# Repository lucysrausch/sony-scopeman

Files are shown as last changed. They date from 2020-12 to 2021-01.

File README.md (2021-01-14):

# Sony-Scopeman
Hardware Design files of a replacement mainboard for the Sony Watchman FD-10. This turns it into a bluetooth and WiFi-enabled vector display.

# Features
There are two modes which can be selected via the power switch. 
* In "Audio" mode, the ESP32 acts as a bluetooth speaker. Play back audio files from your smartphone or laptop to hear and see the soundwaves. You can change the size by adjusting the playback volume

Demo: https://twitter.com/FauthNiklas/status/1337467949318279170
* In "Video" mode, the ESP32 renders the result of the Lorenz Attractor equation. You can change the simulation speed using the "Tune" knob.

Demo: https://twitter.com/FauthNiklas/status/1339650704584171522

# Instructions

You'll need:
* Sony Watchman Model FD-10
* Pre-assembled replacemend mainboard (eg. from JLCPCB assembly)
* Two 803040 (1000mAh) LiIon batterys with JST-PH connector

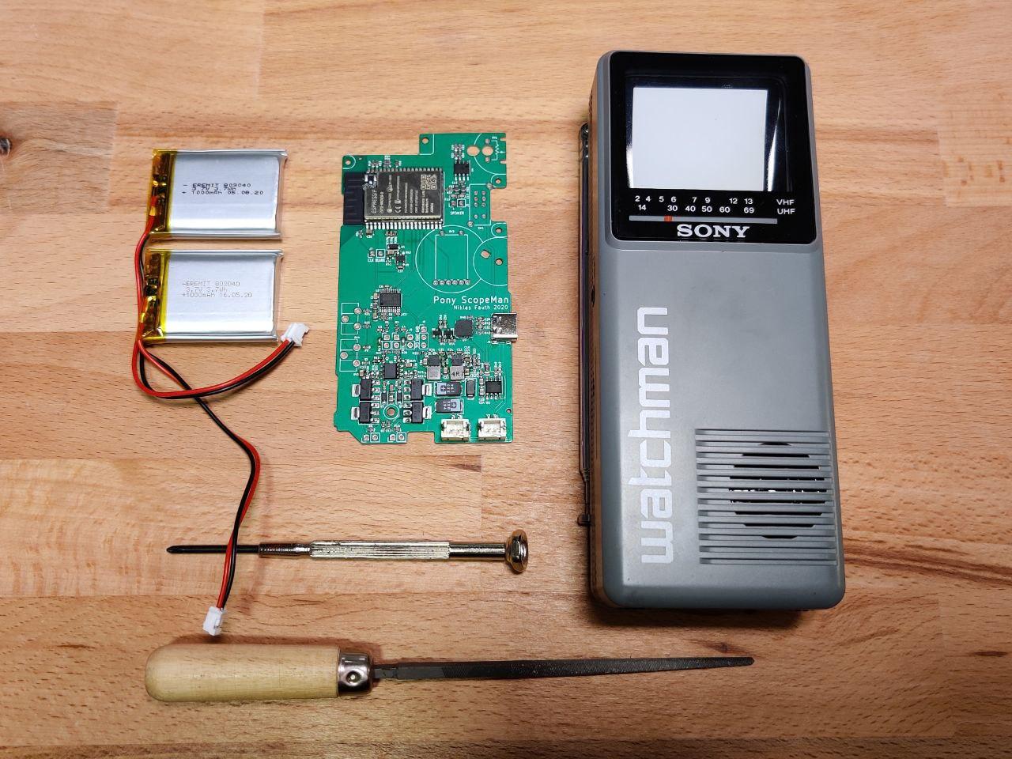
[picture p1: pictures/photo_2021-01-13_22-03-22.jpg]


Open the Sony Watchman and unscrew the original mainboard. Make sure to keep all the screws in a safe place.

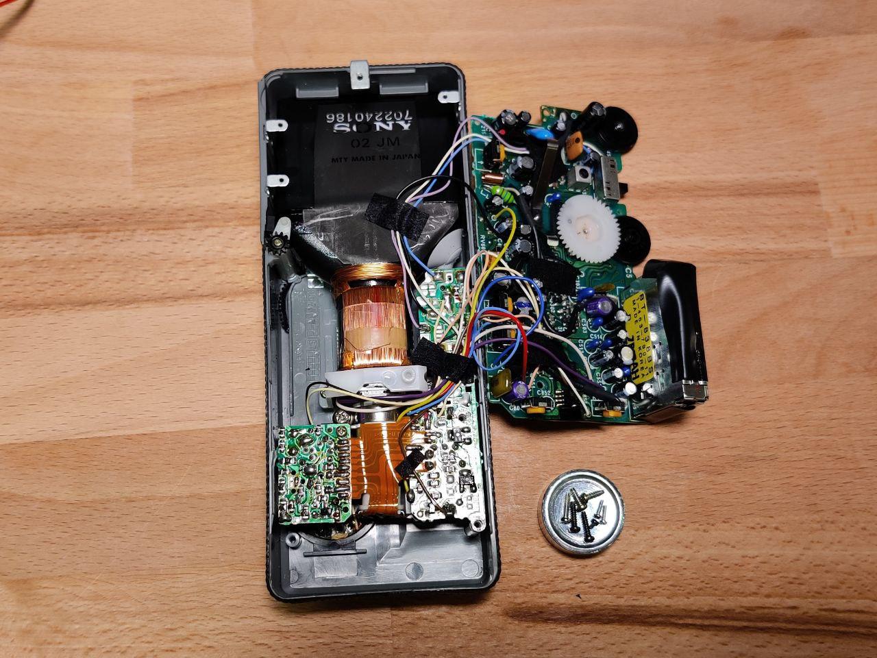
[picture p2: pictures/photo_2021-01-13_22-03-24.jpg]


Unsolder all wires from the mainboard.

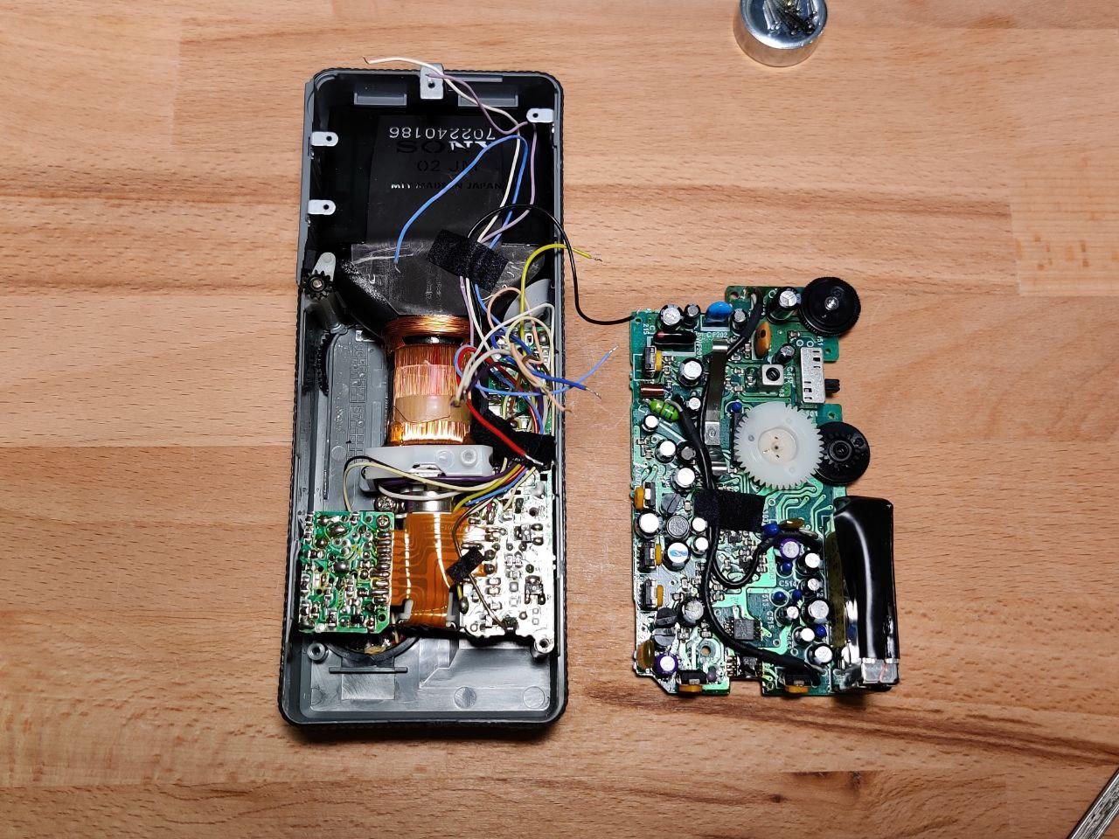
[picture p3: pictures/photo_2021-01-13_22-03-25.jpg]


Unsolder (and unscrew) these components from the mainboard. We'll need them for our replacement.

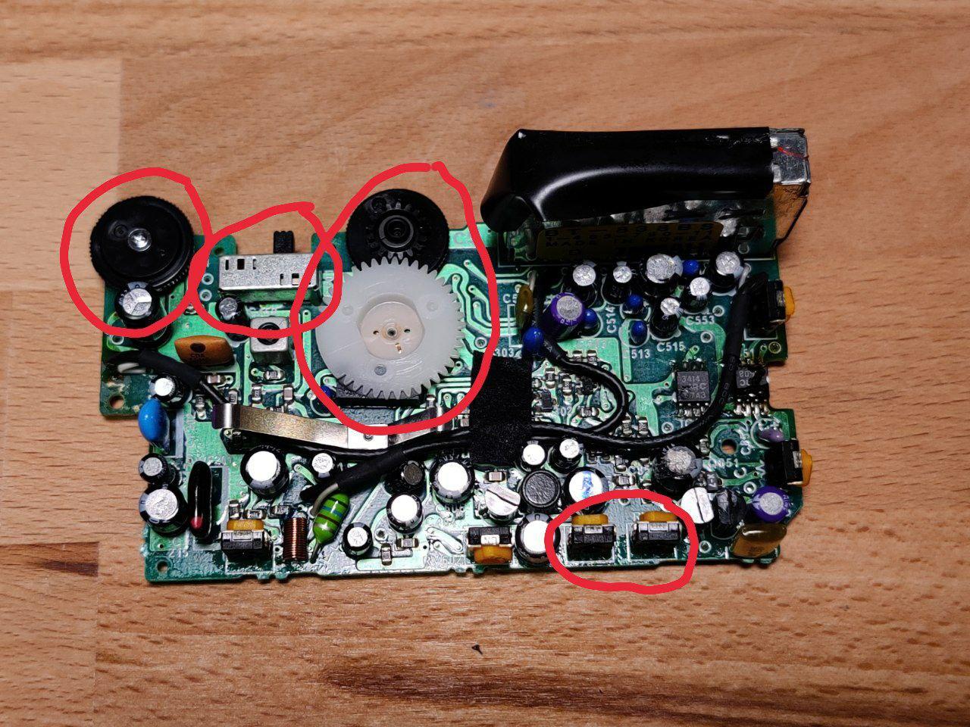
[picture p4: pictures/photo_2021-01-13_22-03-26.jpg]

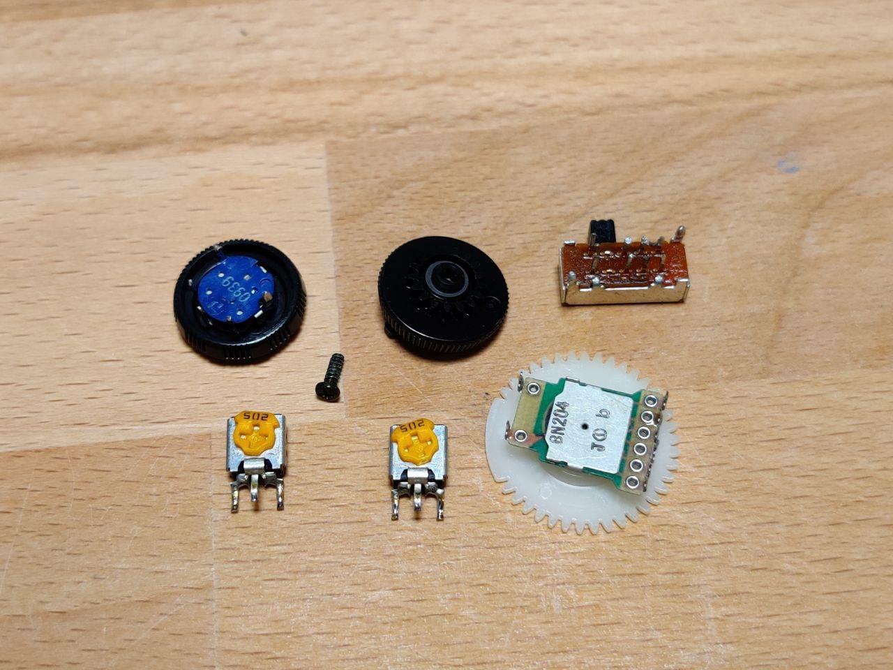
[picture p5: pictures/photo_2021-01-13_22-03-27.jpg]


Install all unsoldered components on the replacement mainboard.

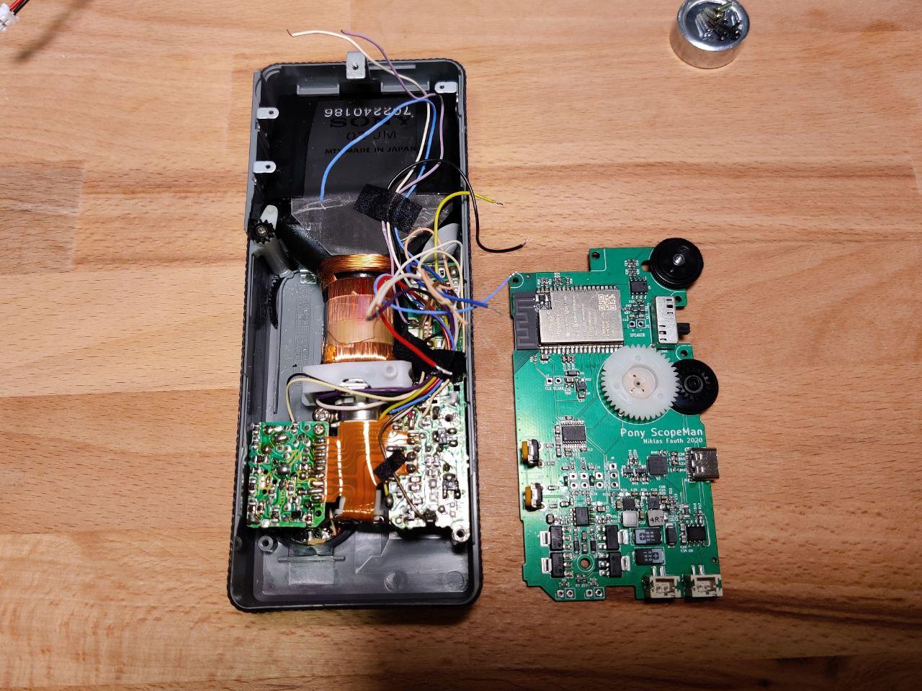
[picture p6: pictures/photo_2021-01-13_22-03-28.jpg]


Unsolder the speaker cables (black and white) from the flyback PCB. Solder them to the replacement PCB (take care of polarity. White is closer to the ESP32).
Remove all other cables from the flyback PCB except for blue, yellow, black and purple.

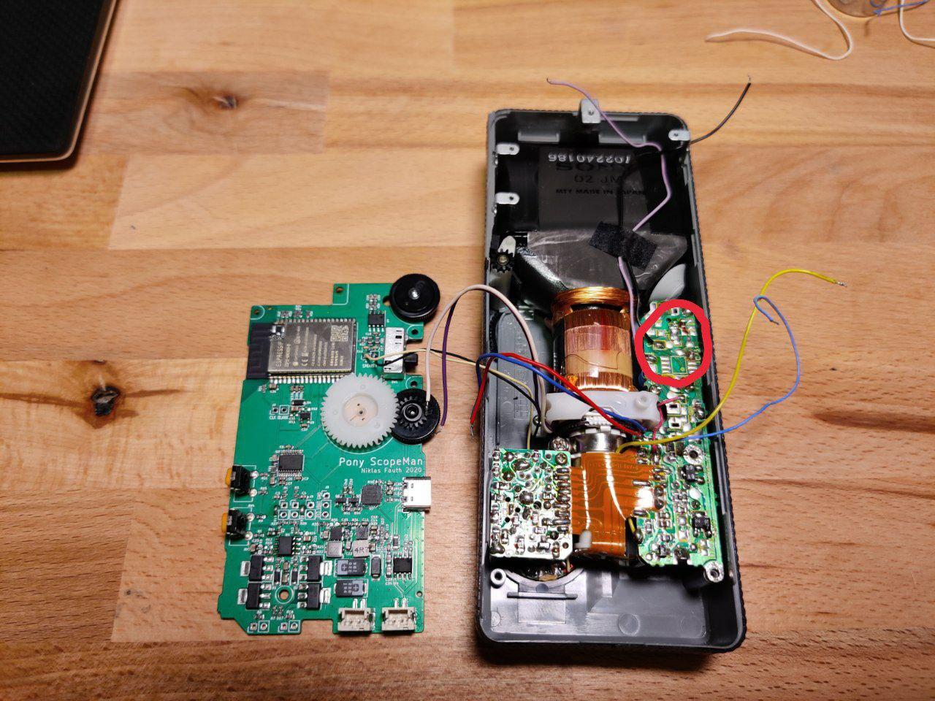
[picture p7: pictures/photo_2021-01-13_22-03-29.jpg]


Solder the blue (flyback signal) and yellow (blanking) to the new mainboard.
Do the same for purple (supply) and black (GND).

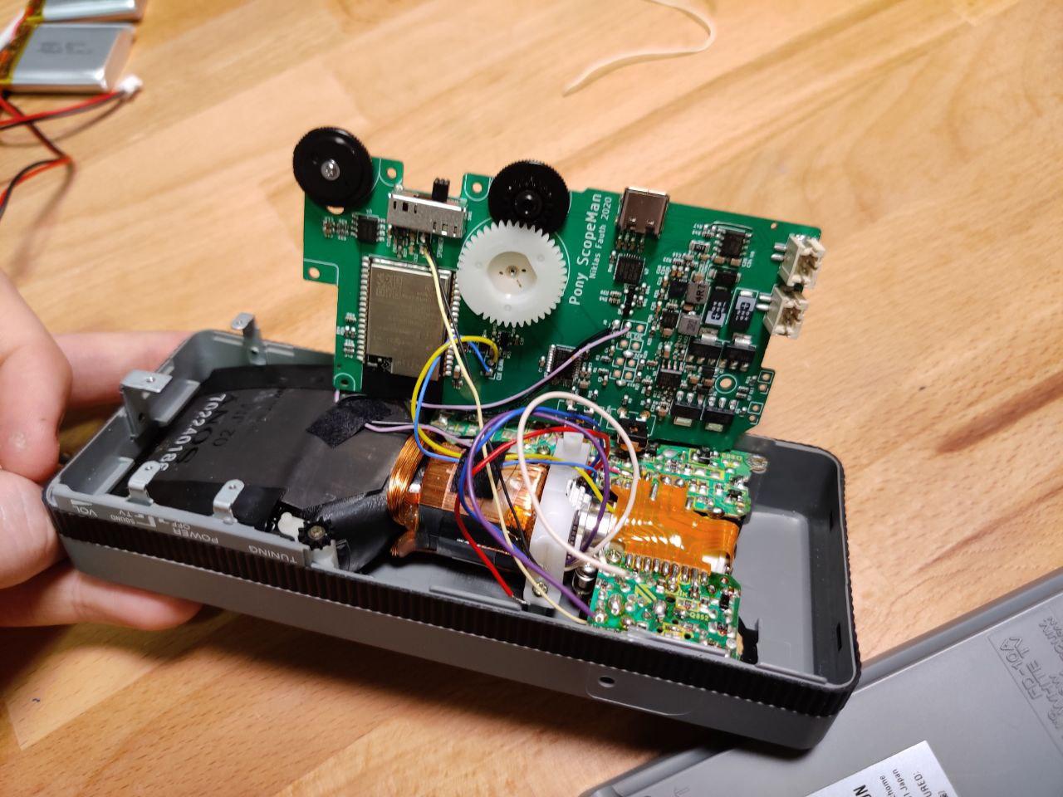
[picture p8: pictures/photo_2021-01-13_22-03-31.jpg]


Next, connect the deflection coil wires (purple, white, red and blue). 

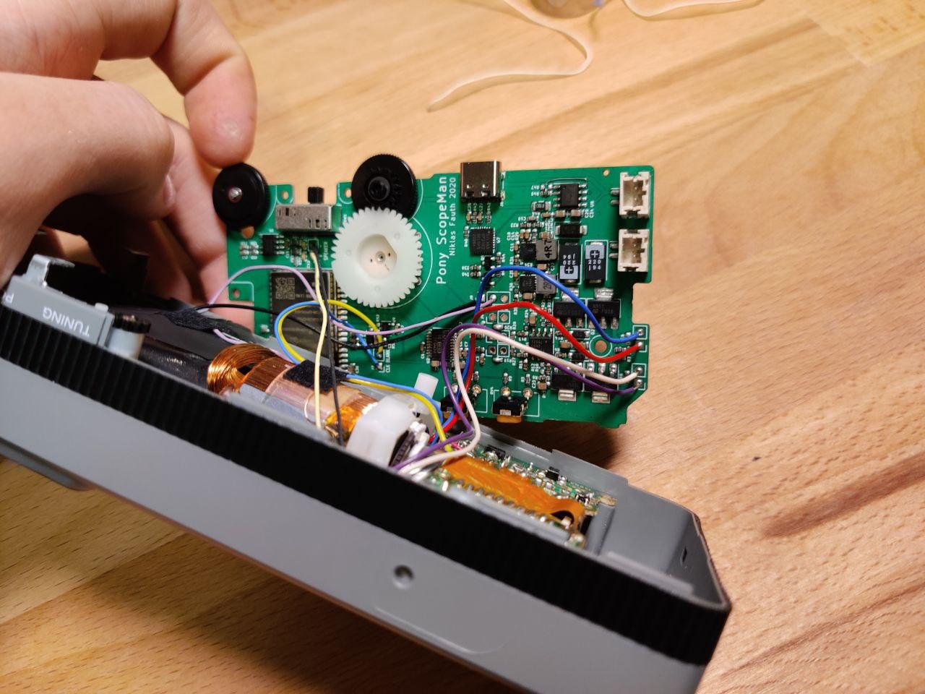
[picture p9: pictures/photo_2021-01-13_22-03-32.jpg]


You can now plug in the batteries (make sure the watchman is turned off) and screw the mainboard back in place. You need two screws for this (mind the arrows on the back of the PCB).

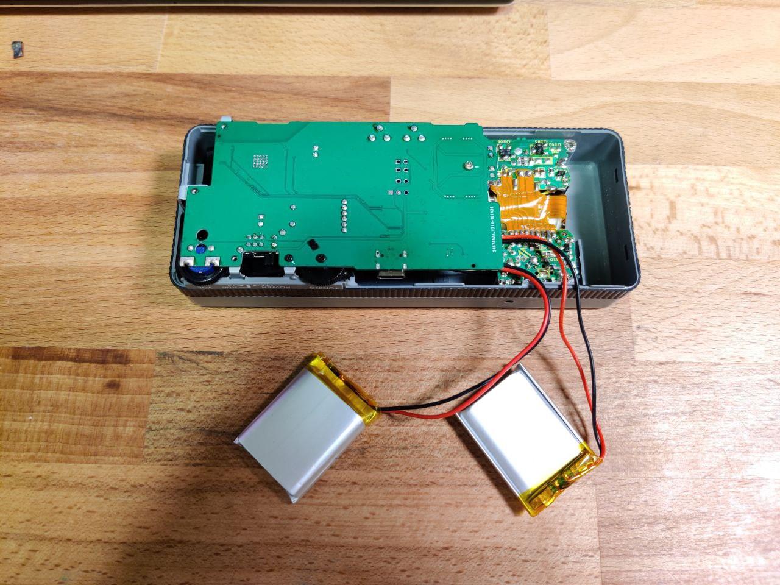
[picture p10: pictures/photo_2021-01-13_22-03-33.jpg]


Now you can add a slothole to the lower half of the case for the USB type C jack. You also need to brake away some plastics to make space for the new batteries. No worries, if done correctly this won't be visible from the outside and the battery cover will still close.

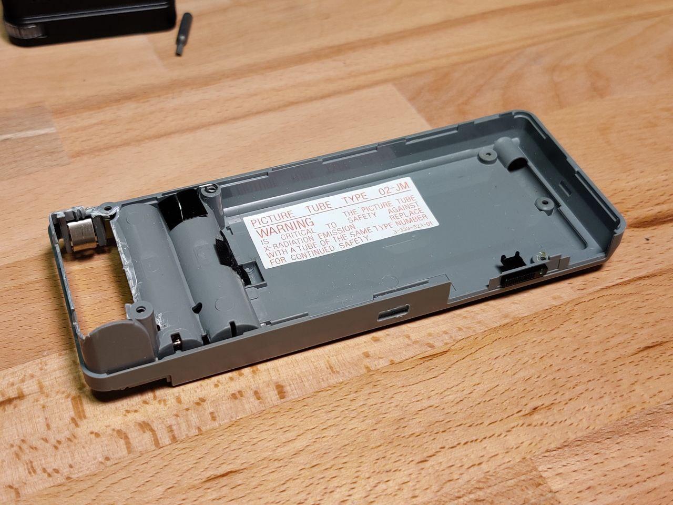
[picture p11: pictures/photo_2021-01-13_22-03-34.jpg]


That's it! Before you screw the watchman back together and store the batteries behind the cover, you may want to adjust the two potentiometers on the mainboard to center the image. But first you need to flash the firmware. Turn on the watchman and connect it via USB. You can then flash the ESP32 using the Arduino IDE (make sure to select "Board: ESP Wrover Module").

You might also need to readjust the focus. This can be done from outside using the original focus knob (hidden behind a small hole at the side).

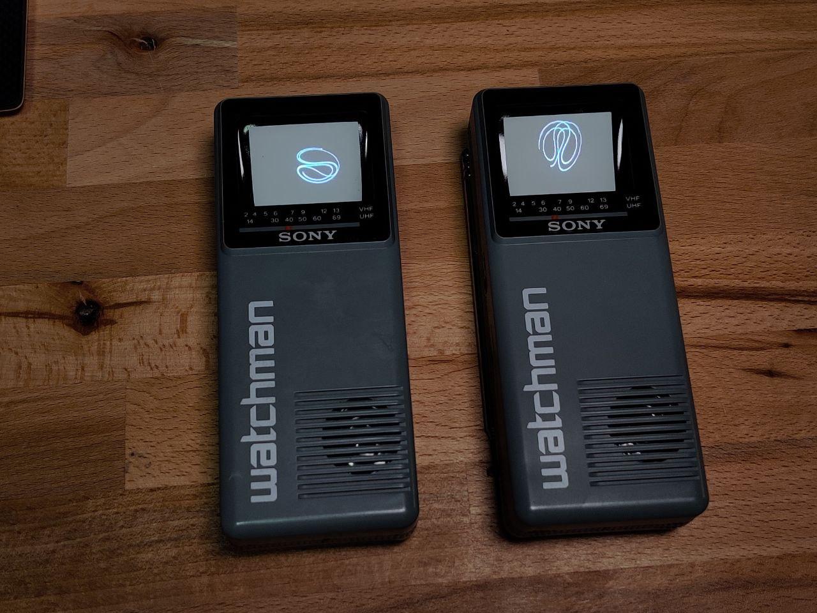
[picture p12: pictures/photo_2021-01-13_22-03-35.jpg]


# Credits
Deflection coil drivers inspired by http://www.e-basteln.de/file/asteroids/Vectrex_XY_Driver.pdf

A2DP Arduino lib for ESP32: https://github.com/pschatzmann/ESP32-A2DP

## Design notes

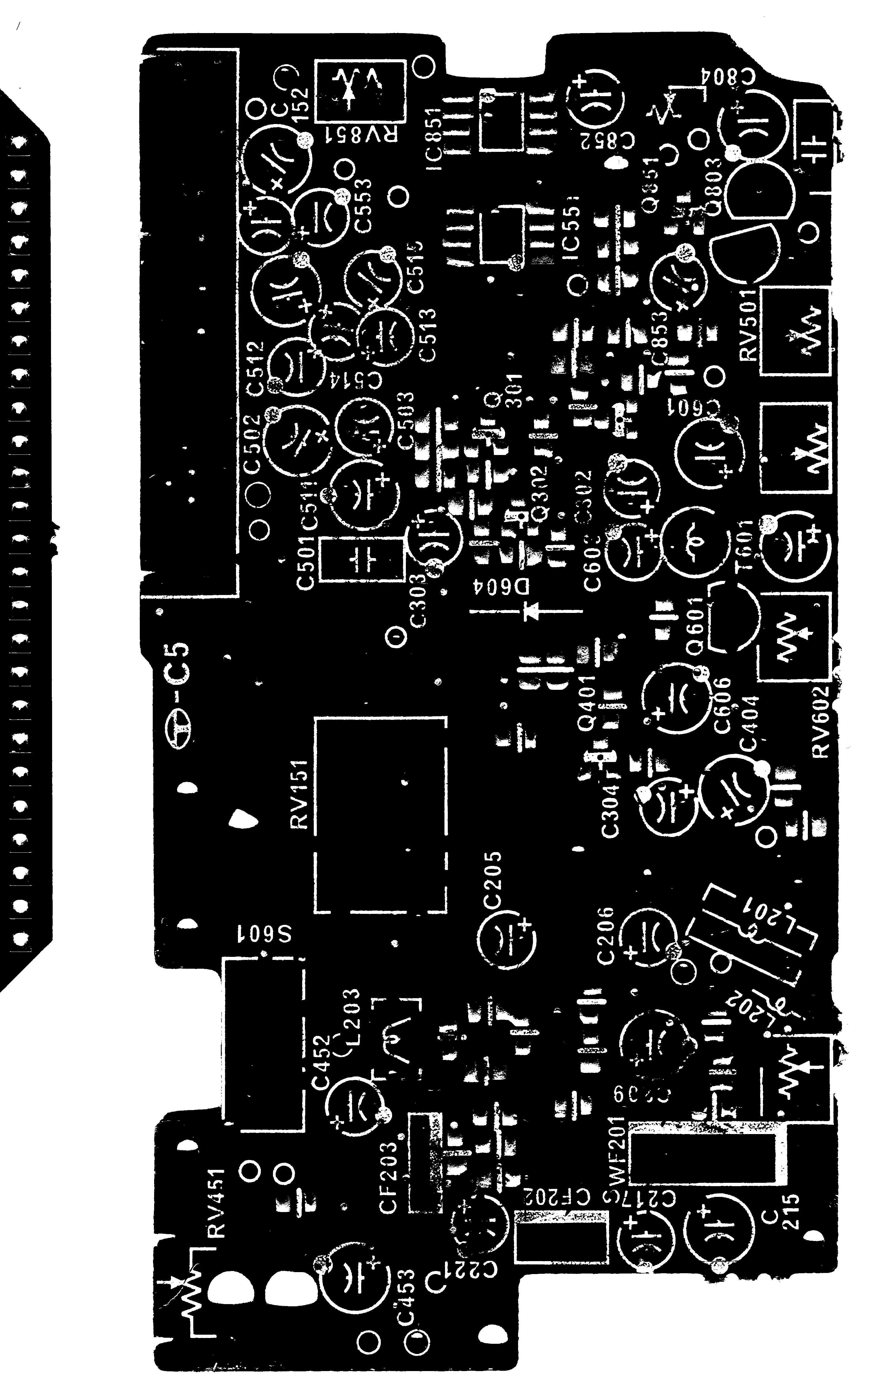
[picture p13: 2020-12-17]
hardware/scans/top.png

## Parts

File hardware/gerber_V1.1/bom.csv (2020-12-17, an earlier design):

Comment | Designator | Footprint | LCSC Part # | LCSC Part Type
100n | C37,C30,C28,C27,C26,C25,C19,C14,C11,C8,C2 | 0603_C | C14663
1k | R55,R54,R17,R13,R7,R2 | 0603_R | C21190
TPS63001 | U6 | Texas_DRC0010J_ThermalVias
TPS63700DRCT | U5 | Texas_DRC0010J_ThermalVias
10u | C36,C35,C34,C31,C29,C24,C23,C22,C21,C20,C9,C5,C1 | 0805_C | C15850
TP4056-otter | U8 | SOIC-8-1EP_3.9x4.9mm_P1.27mm_EP2.41x3.3mm | C16581
0.27R | R46 | R_1206_3216Metric | C25334
LiIon | BT1,BT2 | JST_PH_B2B-PH-SM4-TB_1x02-1MP_P2.00mm_Vertical
MMBT3906 | Q10,Q8 | SOT-23 | C8542
MMBT3904 | Q9,Q7,Q6,Q5 | SOT-23 | C2150
100u | C33,C32 | CP_EIA-7343-43_Kemet-X
10k | RV4,RV3 | Potentiometer_ACP_CA9-H3,8_Horizontal
2.2u | L2 | Inductor_4040
4.7u | L1 | Inductor_4040
GND | J9 | PinHeader_1x02_P2.54mm_Vertical
PWR | J8 | PinHeader_1x03_P2.54mm_Vertical
BLK+CLK | J7 | PinHeader_1x02_P2.54mm_Vertical
SPEAKER | J5 | PinHeader_1x02_P2.54mm_Vertical
COIL_Y | J4 | PinHeader_1x02_P2.54mm_Vertical
EXT_Y | J3 | PinHeader_1x02_P2.54mm_Vertical
COIL_X | J2 | PinHeader_1x02_P2.54mm_Vertical
EXT_X | J1 | PinHeader_1x02_P2.54mm_Vertical
601 | FB3,FB2,FB1 | L_0805_2012Metric | C1017
4148 | D4,D2,D1 | D_SOD-123 | C81598
SL03 | D3 | D_SMA | C8678
LMV321 | U9 | SOT-23-5
CP2102N-A01-GQFN28 | U7 | QFN-28-1EP_5x5mm_P0.5mm_EP3.35x3.35mm | C6568
PAM8302AAD | U4 | SOIC-8_150mil | C112137
ESP32-WROVER | U3 | ESP32-WROVER
PCM5102 | U2 | TSSOP-20_4.4x6.5mm_P0.65mm | C107671
OPA2683 | U1 | SOIC-8_150mil
TBD | R53 | 0603_R
DNP | R52,R36,R24,R20,R19,R11 | 0603_R
22 | R51 | 0603_R | C23345
10k | R50,R47,R45,R44,R41,R40,R39 | 0603_R | C25804
1.2k | R49 | 0603_R | C22765
100k | R48,R38,R37,R33,R23 | 0603_R | C25803
5.1k | R43,R42 | 0603_R | C23186
0R | R35 | 0603_R | C21189
100 | R34,R32,R30 | 0603_R | C22775
10 | R31,R14,R4 | 0603_R | C22859
120k | R29 | 0603_R | C25808
22k | R28,R27,R21,R15,R9,R5 | 0603_R | C31850
220k | R26 | 0603_R | C22961
470 | R25,R22,R12,R10,R3,R1 | 0603_R | C23179
1R | R18,R8 | 0603_R | C22936
3.3k | R16,R6 | 0603_R | C22978
PZT3906 | Q4,Q2 | SOT-223-3_TabPin2
PZT3904 | Q3,Q1 | SOT-223-3_TabPin2
USB_C_Receptacle_USB2.0 | J6 | USB_C_Receptacle_Palconn_UTC16-G
4.7n | C18 | 0603_C | C53987
220p | C17,C12 | 0603_C | C1603
1u | C16,C13 | 0603_C | C15849
10u | C15 | 0603_C | C14663
10pF | C10 | 0603_C | C1634
2.2u | C7,C6 | 0603_C | C23630
2.2n | C4,C3 | 0603_C | C1604
180k | RV2 | sony_tune
10k | RV1 | sony_volume
Power Switch | SW1 | sony_slide_switch

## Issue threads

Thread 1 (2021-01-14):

Awesome Project

minkione, 2021-01-14:
Are years that I am thinking to turn couple of old 5" CRTs into something cool... and here I find your toy!
This 2" CRT handled TV is simply awesome!  Great job! I already ordered a couple of them to try out!

**Questions:**
1) Do you maybe have the service manual of the FD-10A?

2) I was thinking to turn it into a Pong or some vector arcade game (i.e. Asteroids) Do you have any similar plans? In case too coordinate the effort.

NiklasFauth, 2021-01-14:
Hey minkione!

Thanks for your engagement!

1. Unfortunately I do not have the service manual of the FD-10. However, the parts that remain after the mod are very few. It should be possible to reverse engineer the flyback pcb in an afternoon, if required.
2. I do! Not necessarily Pong, but it sure would be fun so see some Vectrex stuff on there. However I haven't tested blanking yet, and I'm unsure how easy it is to sync the internal DAC used for blanking with the external codec controlled via DMA.

In general, it should be fairly easy to implement your own displays. The buffer "buf" is essentially the framebuffer that holds the waveform that generates the display:

https://github.com/NiklasFauth/sony-scopeman/blob/6c2d74821309fc07e94e85a2dcc99b42dd749457/software/scopeman.ino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

This function adds a Cartesian point to the buffer. It should be fairly easy to replace my lorenz attractor with whatever rendering.
Note: Since blanking isn't working yet, the trace of the lorenz attrator is scanned twice, back and forth, so no artifact is visible between the start- and endpoint.

I'm currently moving countries so my time is limited, but I'll sure get back to this at some point. I have the scopeman in my bag all the time, and since it comes with a programmer it's a fun toy to code for on the go.

sudobob, 2021-01-14:
👍 I agree also. Awesome project. BTW) what is wrong with blanking? Is it on the hardware side or software side?

sideburn, 2021-02-24:
Hey guys, I turned a Sony watchman into a pong a couple years ago by removing the video decoder chip and rf module and then using the hackvision library on an arduino nano. I was able to shove the arduino nano into the watchman where the rf module used to be.

There’s a video on YouTube that explains everything: https://youtu.be/PuiLvJbx7Tk

not nearly as awesome as this project though and I’d love to get a pcb manufactured even if I have to do the smd soldering!

TheMetalWizard, 2023-07-20:
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

I know it's been 2 years but the FD-2E has the same daughterboard as the FD-10A. Hope this helps:
http://freeservicemanuals.info/en/servicemanuals/download/Sony/[fd-2e.pdf](http://freeservicemanuals.info/en/servicemanuals/download/Sony/fd-2e.pdf)

If this doesn't work, use this: http://freeservicemanuals.info/en/servicemanuals/viewmanual/Sony/FD2E/

sideburn, 2023-07-20:
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

You can make one into an oscilloscope music device easily by hooking the deflection coil wires to the audio out left and right channels to a Bluetooth module. Here’s a video of one I did: https://youtu.be/3x7MP4MtFiE

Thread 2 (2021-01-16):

bom for Gerber_v1.2

HuubH, 2021-01-16:
Hi, love the project!

I'm planning to order an assembled pcb but am confused on which version of Gerber and bom files I should use on JLCPCB.

When using Gerber_v1.1 with bom from the same folder I get good results on JLCPCB, mixing v1.2 with bom of v1.1 obviously there are errors.

Could you please enlighten me

Best Regards Huub

sealj553, 2021-01-31:
It would also be very helpful to provide a BOM with part numbers, as some of the components are a bit ambiguous. Anyways, thanks Niklas for sharing this project! I'd love to build it soon.

HuubH, 2021-02-02:
Hi,

I just ordered from JLCPCB. 5 PCB's, 2 assembled. I removed some components from the BOM (Q1,Q2,Q3,Q4) That gave me a positive result on JLCPCB. The OPA2683 and USB-C weren't in stock. Have to order those separately.

@NiklasFauth I'm missing the value for resistors with reference TBD. Could you give me the values of these TBD components.

Will report back when my order has arrived and parts are mounted in the Sony.

Again, love this project, bought 2 Sony's on e-bay.  Can't wait for the goods to arrive.

Regards Huub

sealj553, 2021-02-02:
I also ordered some PCBs and parts (already got the Watchman). Hopefully I didn't mess anything up.

@HuubH Not sure if I missed something, but I only see TBD for the 1.1 schematic. Here's what I ordered (1.2):
I got everything from LCSC unless it was cheaper on digikey.
LCSC:
LCSC Part Number | Manufacture Part Number | Manufacturer | Customer NO. | Package | Description | RoHS | Order Qty. | Min\Mult Order Qty. | Unit Price | Order Price
-- | -- | -- | -- | -- | -- | -- | -- | -- | -- | --
C1017 | GZ2012D601TF | Sunlord | FB1,FB2,FB3 | 0805 | Ferrite Beads 600Ω @ 100MHz 500mA 0805 RoHS | Yes | 50 | 50\50 | $0.0192 | $0.96
C1592 | CL10A105KO8NNNC | Samsung Electro-Mechanics | C13,C16 | 0603 | Multilayer Ceramic Capacitors MLCC - SMD/SMT 1uF 16V 0603 RoHS | Yes | 50 | 50\50 | $0.0049 | $0.25
C1603 | CL10B221KB8NNNC | Samsung Electro-Mechanics | C12,C17 | 0603 | Multilayer Ceramic Capacitors MLCC - SMD/SMT 220pF 50V 0603 RoHS | Yes | 50 | 50\50 | $0.0066 | $0.33
C1604 | 0603B222K500NT | FH(Guangdong Fenghua Advanced Tech) | C3,C4 | 0603 | Multilayer Ceramic Capacitors MLCC - SMD/SMT 2.2nF 50V 0603 RoHS | Yes | 50 | 50\50 | $0.0051 | $0.26
C1634 | CL10C100JB8NNNC | Samsung Electro-Mechanics | C10 | 0603 | Multilayer Ceramic Capacitors MLCC - SMD/SMT 10pF 50V 0603 RoHS | Yes | 100 | 50\50 | $0.006 | $0.6
C1691 | CL10A106MQ8NNNC | Samsung Electro-Mechanics | C15 | 0603 | Multilayer Ceramic Capacitors MLCC - SMD/SMT 10uF 6.3V 0603 RoHS | Yes | 50 | 50\50 | $0.0104 | $0.52
C8678 | SS34 | MDD（Microdiode Electronics） | D3 | SMA(DO-214AC) | Schottky Barrier Diodes (SBD) SMA(DO-214AC) RoHS | Yes | 20 | 20\20 | $0.0314 | $0.63
C14663 | CC0603KRX7R9BB104 | YAGEO | C2,C8,C11,C14,C19,.. | 0603 | Multilayer Ceramic Capacitors MLCC - SMD/SMT 100nF 50V 0603 RoHS | Yes | 200 | 50\50 | $0.0044 | $0.88
C15850 | CL21A106KAYNNNE | Samsung Electro-Mechanics | C1,C5,C9,C20,C21,... | 0805 | Multilayer Ceramic Capacitors MLCC - SMD/SMT 10uF 25V 0805 RoHS | Yes | 200 | 20\20 | $0.019 | $3.8
C16581 | TP4056-42-ESOP8 | TOPPOWER(Nanjing Extension Microelectronics) | U8 | ESOP-8 | PMIC - Battery Management ESOP-8 RoHS | Yes | 5 | 1\1 | $0.2123 | $1.06
C18671 | 0603WAJ0753T5E | UNI-ROYAL(Uniroyal Elec) | R29 | 0603 | Chip Resistor - Surface Mount ±5% 0603 RoHS | Yes | 100 | 100\100 | $0.0012 | $0.12
C21190 | 0603WAF1001T5E | UNI-ROYAL(Uniroyal Elec) | R2,R7,R13,R17,R53,.. | 0603 | Chip Resistor - Surface Mount ±1% 0603 RoHS | Yes | 300 | 100\100 | $0.0013 | $0.39
C22765 | 0603WAF1201T5E | UNI-ROYAL(Uniroyal Elec) | R49 | 0603 | Chip Resistor - Surface Mount ±1% 0603 RoHS | Yes | 100 | 100\100 | $0.0019 | $0.19
C22775 | 0603WAF1000T5E | UNI-ROYAL(Uniroyal Elec) | R30,R32,R34 | 0603 | Chip Resistor - Surface Mount ±1% 0603 RoHS | Yes | 100 | 100\100 | $0.0013 | $0.13
C22859 | 0603WAF100JT5E | UNI-ROYAL(Uniroyal Elec) | R4,R14,R31 | 0603 | Chip Resistor - Surface Mount ±1% 0603 RoHS | Yes | 100 | 100\100 | $0.0016 | $0.16
C22961 | 0603WAF2203T5E | UNI-ROYAL(Uniroyal Elec) | R26 | 0603 | Chip Resistor - Surface Mount ±1% 0603 RoHS | Yes | 100 | 100\100 | $0.0012 | $0.12
C22978 | 0603WAF3301T5E | UNI-ROYAL(Uniroyal Elec) | R6,R16 | 0603 | Chip Resistor - Surface Mount ±1% 0603 RoHS | Yes | 100 | 100\100 | $0.0014 | $0.14
C23179 | 0603WAF4700T5E | UNI-ROYAL(Uniroyal Elec) | R1,R3,R10,R11,R22 | 0603 | Chip Resistor - Surface Mount ±1% 0603 RoHS | Yes | 200 | 100\100 | $0.0014 | $0.28
C23345 | 0603WAF220JT5E | UNI-ROYAL(Uniroyal Elec) | R51 | 0603 | Chip Resistor - Surface Mount ±1% 0603 RoHS | Yes | 100 | 100\100 | $0.0012 | $0.12
C23630 | CL10A225KO8NNNC | Samsung Electro-Mechanics | C6,C7 | 0603 | Multilayer Ceramic Capacitors MLCC - SMD/SMT 2.2uF 16V 0603 RoHS | Yes | 50 | 50\50 | $0.0106 | $0.53
C25803 | 0603WAF1003T5E | UNI-ROYAL(Uniroyal Elec) | R23,R33,R37,R38,R48 | 0603 | Chip Resistor - Surface Mount ±1% 0603 RoHS | Yes | 200 | 100\100 | $0.0013 | $0.26
C25804 | 0603WAF1002T5E | UNI-ROYAL(Uniroyal Elec) | R5,R9,R15,R21,R39,.. | 0603 | Chip Resistor - Surface Mount ±1% 0603 RoHS | Yes | 300 | 100\100 | $0.0014 | $0.42
C28060 | TPS63001DRCR | Texas Instruments | U6 | VSON-10 | DC-DC Converters Step-Up/Step-Down Fixed 1 1.8V 5.5V 3.3V 1.6A (Switch) VSON-10 RoHS | Yes | 10 | 1\1 | $0.954 | $9.54
C53987 | 0603B472K500NT | FH(Guangdong Fenghua Advanced Tech) | C18 | 0603 | Multilayer Ceramic Capacitors MLCC - SMD/SMT 4.7nF 50V 0603 RoHS | Yes | 50 | 50\50 | $0.0051 | $0.26
C54792 | TPS63700DRCR | Texas Instruments | U5 | SON-10 | DC-DC Converters Step-Up/Step-Down Adjustable 1 2.7V 5.5V -2V -15V 360mA SON-10 RoHS | Yes | 4 | 1\1 | $1.4445 | $5.78
C81598 | 1N4148W | ST(Semtech) | D1,D2,D4 | SOD-123 | Switching Diode 75V 150mA 1.25V @ 150mA 4ns SOD-123 RoHS | Yes | 50 | 50\50 | $0.0131 | $0.66
C107671 | PCM5102APWR | Texas Instruments | U2 | TSSOP-20 | Digital To Analog Converters (DACs) TSSOP-20 RoHS | Yes | 10 | 1\1 | $1.98 | $19.8
C111113 | MMBT3904 | Shikues | Q1,Q3,Q5,Q6 | SOT-23(SOT-23-3) | Transistors (NPN/PNP) NPN 200mA 40V SOT-23(SOT-23-3) RoHS | Yes | 100 | 50\50 | $0.0075 | $0.75
C111114 | MMBT3906 | Shikues | Q2,Q4 | SOT-23(SOT-23-3) | Transistors (NPN/PNP) PNP 200mA 40V SOT-23(SOT-23-3) RoHS | Yes | 50 | 50\50 | $0.0072 | $0.36
C112137 | PAM8302AADCR | Diodes Incorporated | U4 | SOP-8_150mil | Audio Power OpAmps SOP-8_150mil RoHS | Yes | 10 | 1\1 | $0.1545 | $1.55
C133359 | STN851 | STMicroelectronics | Q7,Q9 | SOT-223 | Transistors (NPN/PNP) NPN 5A 60V SOT-223 RoHS | Yes | 5 | 1\1 | $0.2493 | $1.25
C133360 | STN951 | STMicroelectronics | Q8,Q10 | SOT-223 | Transistors (NPN/PNP) PNP 5A 60V SOT-223 RoHS | Yes | 5 | 1\1 | $0.2932 | $1.47
C134092 | 1054500101 | MOLEX | J6 | Through Hole | USB Connectors Through Hole RoHS | Yes | 3 | 1\1 | $0.7737 | $2.32
C155463 | 293D107X9010D2TE3 | Vishay Intertech | C32,C33 | CASE-D_7343 | Tantalum Capacitors 100uF 10V CASE-D_7343 RoHS | Yes | 10 | 1\1 | $0.2696 | $2.7
C157955 | PHR-2 | JST Sales America | BT1_M,BT2_M | P=2mm | Rectangular Connectors Housings P=2mm RoHS | Yes | 50 | 50\50 | $0.0133 | $0.67
C160352 | B2B-PH-SM4-TB(LF)(SN) | JST Sales America | BT1,BT2 | SMD,P=2mm | Wire To Board / Wire To Wire Connector SMD,P=2mm RoHS | Yes | 12 | 1\1 | $0.1218 | $1.46
C189432 | PZT3904 | Changjiang Electronics Tech (CJ) | Q1,Q3 | SOT-223 | Transistors (NPN/PNP) NPN 200mA 40V SOT-223 RoHS | Yes | 20 | 10\10 | $0.0546 | $1.09
C217885 | ARG03FTC2202 | Viking Tech | R27,R28 | 0603 | High Precision & Low TCR SMD Resistors 22KOhms ±1% 1/10W 0603 RoHS | Yes | 50 | 50\50 | $0.0091 | $0.46
C308471 | MCR18EZHFLR270 | ROHM Semicon | R46 | 1206 | Low Resistors & Current Sense Resistors - Surface Mount 0.27ΩOhms ±1% 1/4W 1206 RoHS | Yes | 10 | 10\10 | $0.0741 | $0.74
C311919 | ARG03DTC5101 | Viking Tech | R42,R43 | 0603 | High Precision & Low TCR SMD Resistors 5.1KOhms ±0.5% 1/10W 0603 RoHS | Yes | 50 | 50\50 | $0.0081 | $0.41
C365182 | HPCR0603F4R70K9 | Resistor.Today | R8,R18 | 0603 | High power surface mount resistance 0603 RoHS | Yes | 20 | 10\10 | $0.0409 | $0.82
C520302 | CR4018-2R2M | Ceaiya | L2 | SMD,4.0x4.0x1.85mm | Power Inductors 2.2uH ±20% 2A SMD,4.0x4.0x1.85mm RoHS | Yes | 10 | 10\10 | $0.0444 | $0.44
C520304 | CR4018-4R7M | Ceaiya | L1 | SMD,4.0x4.0x1.85mm | Power Inductors 4.7uH ±20% 1.7A SMD,4.0x4.0x1.85mm RoHS | Yes | 10 | 10\10 | $0.0444 | $0.44
C686637 | LMV321 | PJSEMI | U9 | SOT-23-5 | Low Power OpAmps SOT-23-5 RoHS | Yes | 10 | 10\10 | $0.0574 | $0.57

Digikey:

Quantity | Part Number | Description | Customer Reference | Unit Price | Extended Price | URL
-- | -- | -- | -- | -- | -- | --
3 | 296-14172-5-ND  OPA2683ID | IC OPAMP CFA 2 CIRCUIT 8SOIC | U1 | 5.96 | $17.88 | https://www.digikey.com/product-detail/en/texas-instruments/OPA2683ID/296-14172-5-ND/525999
4 | 2073-USB4125-GF-ACT-ND  USB4125-GF-A | USB C REC, GF, RA, 6P, SMT, TH S | J6 | 0.67 | $2.68 | https://www.digikey.com/product-detail/en/gct/USB4125-GF-A/2073-USB4125-GF-ACT-ND/13547384
4 | 336-5890-1-ND  CP2102N-A02-GQFN28R | IC USB TO UART BRIDGE QFN28 | U7 | 1.4 | $5.60 | https://www.digikey.com/product-detail/en/silicon-labs/CP2102N-A02-GQFN28R/336-5890-1-ND/9863483
3 | 1965-ESP32-WROVER-E(16MB)CT-ND  ESP32-WROVER-E (16MB) | RX TXRX MOD WIFI PCB TRACE SMD | U3 | 3.28 | $9.84 | https://www.digikey.com/product-detail/en/espressif-systems/ESP32-WROVER-E-(16MB)/1965-ESP32-WROVER-E(16MB)CT-ND/11613147

HuubH, 2021-02-02:
Hi,

I used the BOM of V1.1 and roughly checked the differences in component used in the schematics of both. Then used this list with the V1.2 Gerber files to order pcb's incl. parts placement.

The PDF schematic file and the Kicad schematic V1.2 contain R12, R24, R25, R36, R52 which show a " DNP" value in my case. (Not TBD as mentioned before. Sorry for the typo.  )

Looking at your list, these part numbers are not listed or maybe not shown and somehow cutoff in row C25804?

Hope I didn't make a mistake somewhere,

@sealj553 If you can provide me with the value of those components that would be great.

Huub

sealj553, 2021-02-02:
I believe DNP means "do not populate/place", so you should be able to just
leave those out.

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

HuubH, 2021-02-02:
Ah, thanks a lot for that piece of information. That gives me some peace of mind 👍

> I believe DNP means "do not populate/place", so you should be able to just leave those out.
> […](#)

HuubH, 2021-02-16:
@sealj553 After some tinkering got it working :)

@NiklasFauth Thanks again for sharing the project

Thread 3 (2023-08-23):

compatibility with other watchmen

kritzikratzi, 2023-08-23:
hi!

this is a great project and i'd love to try to make one for myself.

is this compatible with any other watchmen? i've been tracking the second hand market in my county and i find FD-20, FD-2E, and many very similar looking ones, but no FD-10.

kritzikratzi, 2023-09-29:
well, i solved it buy getting the fd-10 from across the sea. all the parts and circuit board are here now, wish me luck :)

kritzikratzi, 2023-11-17:
hey!

ok, i managed to build one, and i would like to do _something_ with this ^^
do you have any contact where i can reach you? (you can contact me at super@superduper.org -- gonna delete this soon, as i don't need to have my email out in the public)

best, hansi.

Closed 2023-09-29.

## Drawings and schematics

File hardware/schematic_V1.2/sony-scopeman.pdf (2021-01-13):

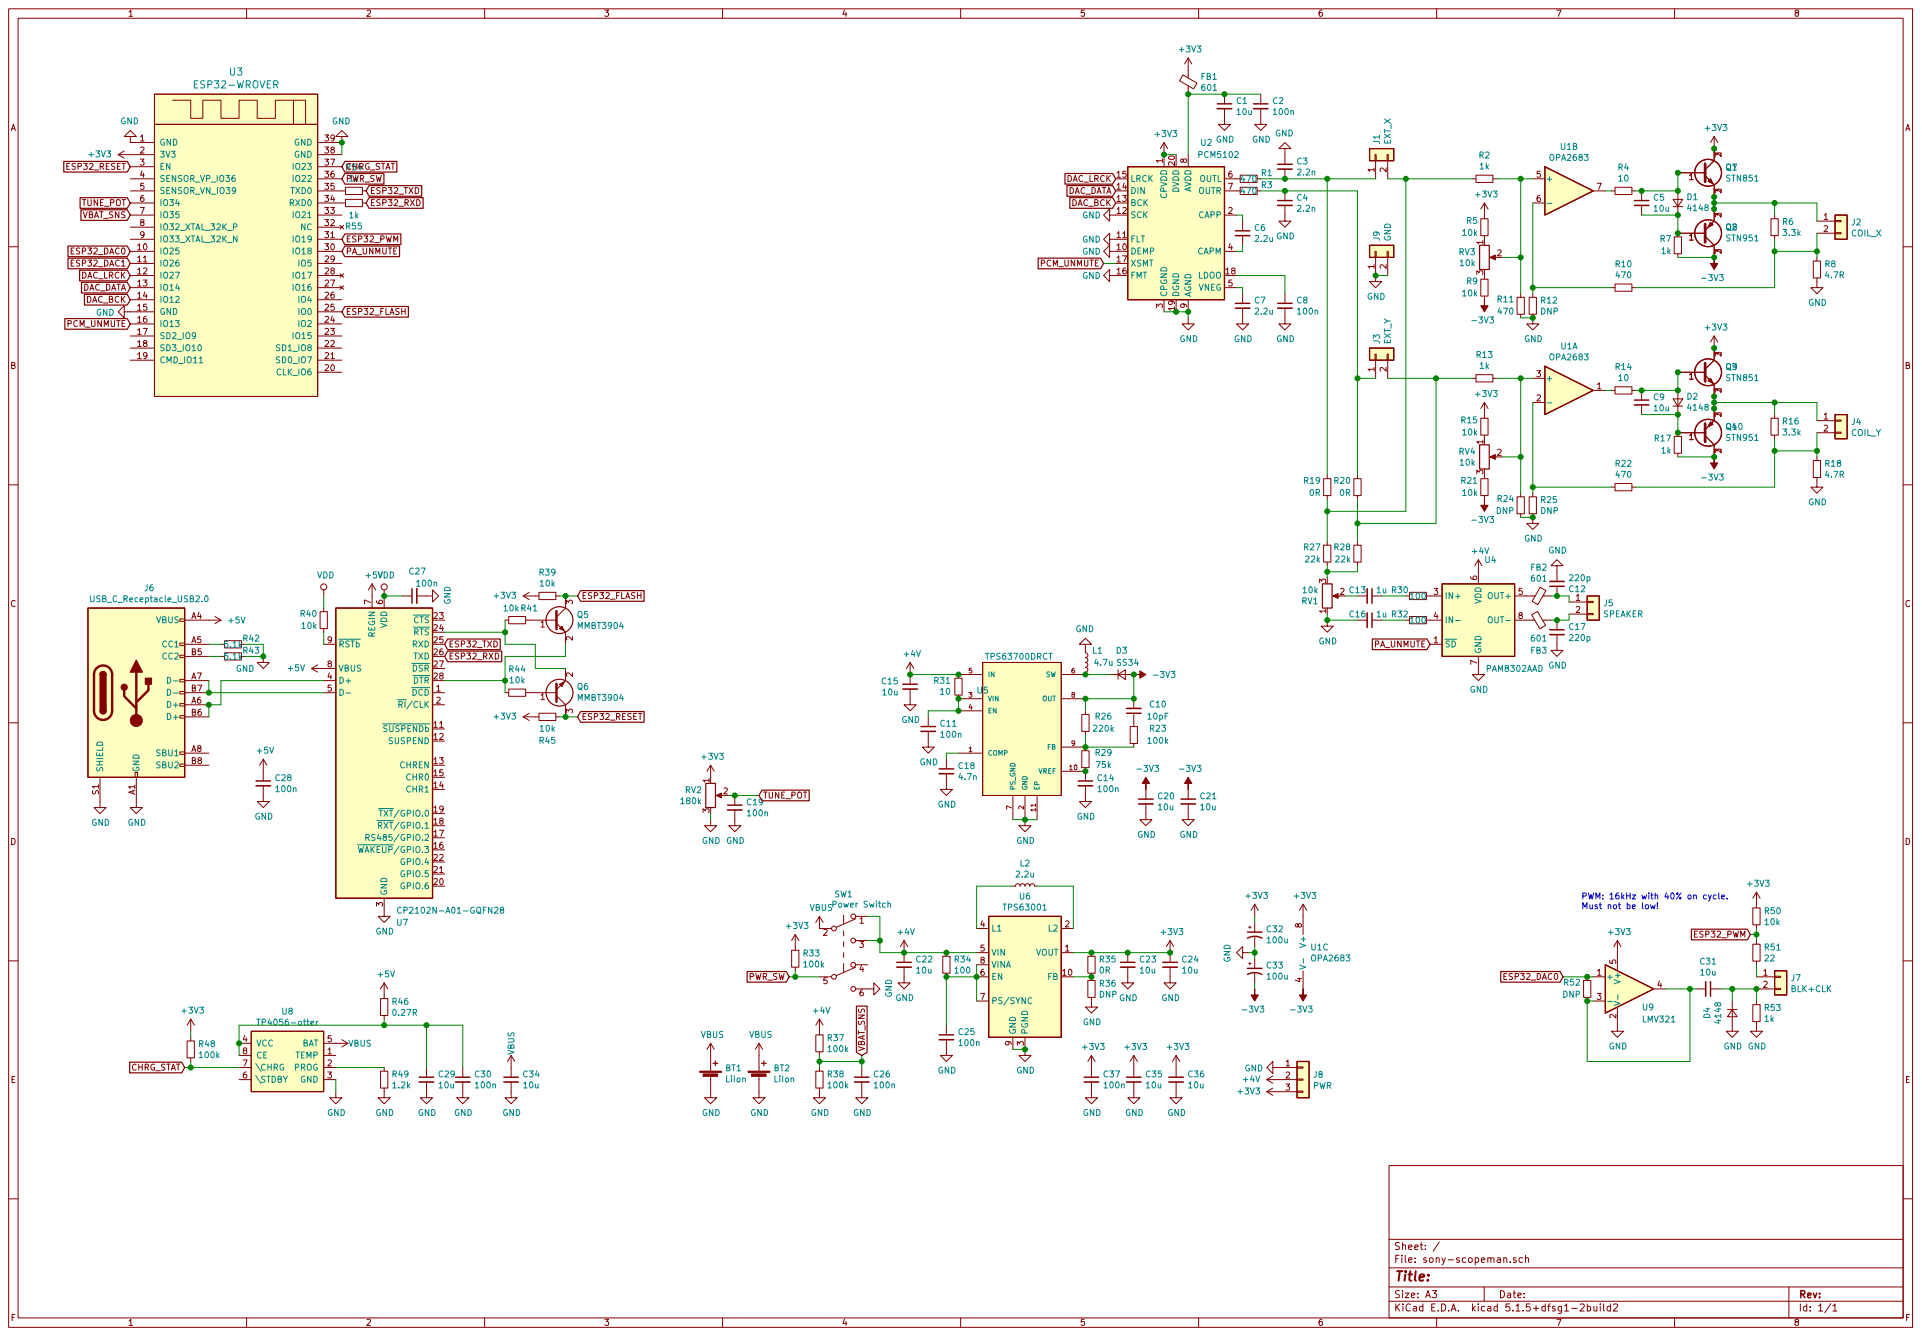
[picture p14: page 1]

1 DEMP 10 FLT 11 SCK 12 BCK 13 DIN 14

3 CAPM 4 VNEG 5 OUTL 6 OUTR 7 AVDD

PWM: 16kHz with 40% on cycle. Must not be low!
+3V3 GNDV- 2 V+

File: sony-scopeman.sch Sheet: /

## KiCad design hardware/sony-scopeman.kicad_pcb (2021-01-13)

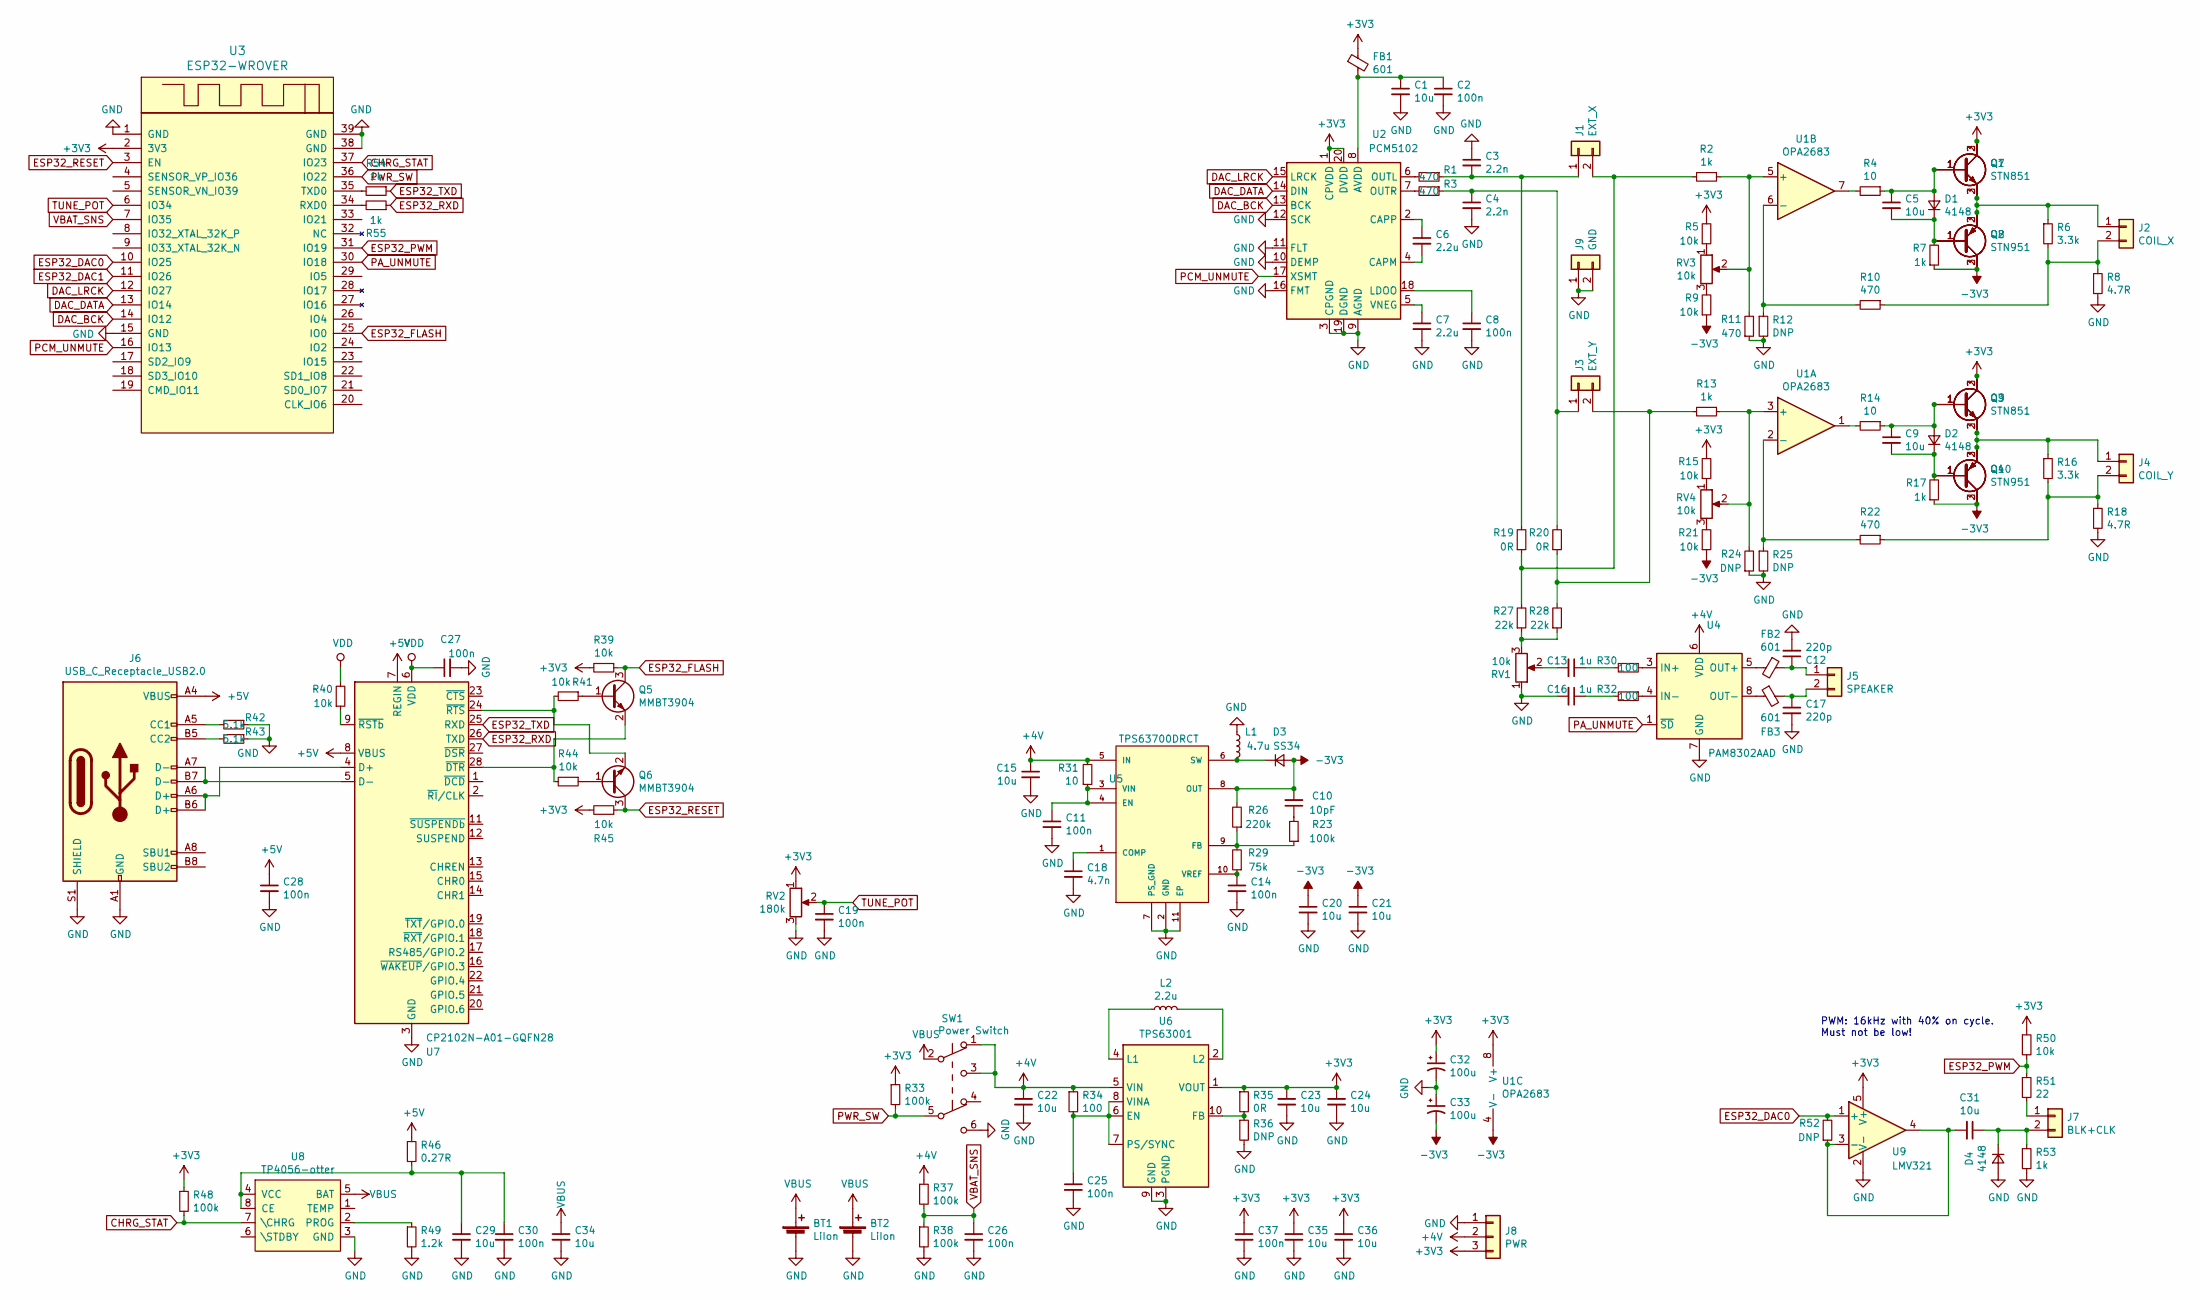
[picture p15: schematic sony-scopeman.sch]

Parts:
BT1, BT2: LiIon; JST_PH_B2B-PH-SM4-TB_1x02-1MP_P2.00mm_Vertical
C1, C5, C9, C20, C21, C22, C23, C24, C29, C31, C34, C35, C36: 10u; C_0805_2012Metric
C2, C8, C11, C14, C19, C25, C26, C27, C28, C30, C37: 100n; C_0603_1608Metric
C3, C4: 2.2n; C_0603_1608Metric
C6, C7: 2.2u; C_0603_1608Metric
C10: 10pF; C_0603_1608Metric
C12, C17: 220p; C_0603_1608Metric
C13, C16: 1u; C_0603_1608Metric
C15: 10u; C_0603_1608Metric
C18: 4.7n; C_0603_1608Metric
C32, C33: 100u; CP_EIA-7343-43_Kemet-X
D1, D2, D4: 4148; D_SOD-123
D3: SS34; D_SMA
FB1, FB2, FB3: 601; L_0805_2012Metric
J1: EXT_X; PinHeader_1x02_P2.54mm_Vertical
J2: COIL_X; PinHeader_1x02_P2.54mm_Vertical
J3: EXT_Y; PinHeader_1x02_P2.54mm_Vertical
J4: COIL_Y; PinHeader_1x02_P2.54mm_Vertical
J5: SPEAKER; PinHeader_1x02_P2.54mm_Vertical
J6: USB_C_Receptacle_USB2.0; USB_C_Receptacle_Palconn_UTC16-G
J7: BLK+CLK; PinHeader_1x02_P2.54mm_Vertical
J8: PWR; PinHeader_1x03_P2.54mm_Vertical
J9: GND; PinHeader_1x02_P2.54mm_Vertical
L1: 4.7u; Inductor_4040
L2: 2.2u; Inductor_4040
Q1, Q3: PZT3904; SOT-223-3_TabPin2
Q2, Q4: PZT3906; SOT-223-3_TabPin2
Q5, Q6: MMBT3904; SOT-23
Q7, Q9: STN851; SOT-23
Q8, Q10: STN951; SOT-23
R1, R3, R10, R11, R22: 470; R_0603_1608Metric
R2, R7, R13, R17, R53, R54, R55: 1k; R_0603_1608Metric
R4, R14, R31: 10; R_0603_1608Metric
R5, R9, R15, R21, R39, R40, R41, R44, R45, R50: 10k; R_0603_1608Metric
R6, R16: 3.3k; R_0603_1608Metric
R8, R18: 4.7R; R_0603_1608Metric
R12, R24, R25, R36, R52: DNP; R_0603_1608Metric
R19, R20, R35: 0R; R_0603_1608Metric
R23, R33, R37, R38, R48: 100k; R_0603_1608Metric
R26: 220k; R_0603_1608Metric
R27, R28: 22k; R_0603_1608Metric
R29: 75k; R_0603_1608Metric
R30, R32, R34: 100; R_0603_1608Metric
R42, R43: 5.1k; R_0603_1608Metric
R46: 0.27R; R_1206_3216Metric
R49: 1.2k; R_0603_1608Metric
R51: 22; R_0603_1608Metric
RV1: 10k; sony_volume
RV2: 180k; sony_tune
RV3, RV4: 10k; Potentiometer_ACP_CA9-H3,8_Horizontal
SW1: Power Switch; sony_slide_switch
U1: OPA2683; SOIC-8_3.9x4.9mm_P1.27mm
U2: PCM5102; TSSOP-20_4.4x6.5mm_P0.65mm
U3: ESP32-WROVER
U4: PAM8302AAD; SOIC-8_3.9x4.9mm_P1.27mm
U5: TPS63700DRCT; Texas_DRC0010J_ThermalVias
U6: TPS63001; Texas_DRC0010J_ThermalVias
U7: CP2102N-A01-GQFN28; QFN-28-1EP_5x5mm_P0.5mm_EP3.35x3.35mm
U8: TP4056-otter; SOIC-8-1EP_3.9x4.9mm_P1.27mm_EP2.41x3.3mm
U9: LMV321; SOT-23-5

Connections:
+3V3: C23.1, C24.1, C32.1, C35.1, C36.1, C37.1, FB1.1, J8.3, Q1.2 (C), Q1.4 (C), Q3.2 (C), Q3.4 (C), Q7.3 (C), Q9.3 (C), R5.2, R15.2, R33.1, R35.1, R39.2, R45.2, R48.1, R50.1, RV2.1, U1.8 (V+), U2.1 (CPVDD), U2.20 (DVDD), U3.2 (3V3), U6.1 (VOUT), U9.5 (V+)
+4V: C15.1, C22.1, J8.2, R31.2, R34.1, R37.1, SW1.1 (A), SW1.3 (C), U4.6 (VDD), U5.5 (IN), U6.5 (VIN)
+5V: C28.1, J6.A4 (VBUS), J6.A9 (VBUS), J6.B4 (VBUS), J6.B9 (VBUS), R46.1, U7.7 (REGIN), U7.8 (VBUS)
-3V3: C10.2, C20.1, C21.1, C33.2, D3.2 (A), Q2.2 (C), Q2.4 (C), Q4.2 (C), Q4.4 (C), Q8.3 (C), Q10.3 (C), R7.1, R9.1, R17.1, R21.1, R26.2, U1.4 (V-), U5.8 (OUT)
CHRG_STAT: R48.2, U3.37 (IO23), U8.7 (\CHRG)
DAC_BCK: U2.13 (BCK), U3.14 (IO12)
DAC_DATA: U2.14 (DIN), U3.13 (IO14)
DAC_LRCK: U2.15 (LRCK), U3.12 (IO27)
ESP32_DAC0: R52.2, U3.10 (IO25), U9.1 (+)
ESP32_DAC1: U3.11 (IO26)
ESP32_FLASH: Q5.3 (C), R39.1, U3.25 (IO0)
ESP32_PWM: R50.2, R51.1, U3.31 (IO19)
ESP32_RESET: Q6.3 (C), R45.1, U3.3 (EN)
ESP32_RXD: R55.1, U7.26 (TXD)
ESP32_TXD: R54.1, U7.25 (RXD)
GND: BT1.2 (-), BT2.2 (-), C1.2, C2.2, C3.1, C4.2, C7.2, C8.2, C11.2, C12.2, C14.2, C15.2, C16.2, C17.2, C18.2, C19.2, C20.2, C21.2, C22.2, C23.2, C24.2, C25.2, C26.2, C27.2, C28.2, C29.2, C30.2, C32.2, C33.1, C34.2, C35.2, C36.2, C37.2, D4.2 (A), J6.A1 (GND), J6.A12 (GND), J6.B1 (GND), J6.B12 (GND), J6.S1 (SHIELD), J8.1, J9.1, J9.2, L1.1, R8.2, R11.1, R12.2, R18.2, R24.1, R25.2, R36.2, R38.2, R42.1, R43.1, R49.2, R53.2, RV1.1, RV2.3, SW1.6 (C), U2.3 (CPGND), U2.9 (AGND), U2.10 (DEMP), U2.11 (FLT), U2.12 (SCK), U2.16 (FMT), U2.19 (DGND), U3.1 (GND), U3.15 (GND), U3.38 (GND), U3.39 (GND), U4.7 (GND), U5.2 (GND), U5.7 (PS_GND), U5.11 (EP), U6.3 (PGND), U6.9 (GND), U6.11 (PGND), U7.3 (GND), U7.29 (GND), U8.3 (GND), U8.9 (GND), U9.2 (V-)
unnamed: C1.1, C2.1, FB1.2, U2.8 (AVDD)
unnamed: C3.2, J1.1, R1.1, R19.2
unnamed: C4.1, J3.1, R3.1, R20.2
unnamed: C5.1, D1.2 (A), Q1.1 (B), Q7.1 (B), R4.1
unnamed: C5.2, D1.1 (K), Q2.1 (B), Q8.1 (B), R7.2
unnamed: C6.1, U2.2 (CAPP)
unnamed: C6.2, U2.4 (CAPM)
unnamed: C7.1, U2.5 (VNEG)
unnamed: C8.1, U2.18 (LDOO)
unnamed: C9.1, D2.2 (A), Q3.1 (B), Q9.1 (B), R14.1
unnamed: C9.2, D2.1 (K), Q4.1 (B), Q10.1 (B), R17.2
unnamed: C10.1, R23.2
unnamed: C11.1, R31.1, U5.3 (VIN), U5.4 (EN)
unnamed: C12.1, FB2.1, J5.1
unnamed: C13.1, R30.2
unnamed: C13.2, RV1.2
unnamed: C14.1, R29.1, U5.10 (VREF)
unnamed: C16.1, R32.2
unnamed: C17.1, FB3.2, J5.2
unnamed: C18.1, U5.1 (COMP)
unnamed: C25.1, R34.2, U6.6 (EN), U6.7 (PS/SYNC), U6.8 (VINA)
unnamed: C29.1, C30.1, R46.2, U8.4 (VCC), U8.8 (CE)
unnamed: C31.1, D4.1 (K), J7.2, R53.1
unnamed: C31.2, R52.1, U9.3 (-), U9.4
unnamed: D3.1 (K), L1.2, U5.6 (SW)
unnamed: FB2.2, U4.5 (OUT+)
unnamed: FB3.1, U4.8 (OUT-)
unnamed: J1.2, R2.2, R19.1, R27.2
unnamed: J2.1, Q1.3 (E), Q2.3 (E), Q7.2 (E), Q8.2 (E), R6.1
unnamed: J2.2, R6.2, R8.1, R10.1
unnamed: J3.2, R13.2, R20.1, R28.2
unnamed: J4.1, Q3.3 (E), Q4.3 (E), Q9.2 (E), Q10.2 (E), R16.1
unnamed: J4.2, R16.2, R18.1, R22.1
unnamed: J6.A5 (CC1), R42.2
unnamed: J6.A6 (D+), J6.B6 (D+), U7.4 (D+)
unnamed: J6.A7 (D-), J6.B7 (D-), U7.5 (D-)
unnamed: J6.B5 (CC2), R43.2
unnamed: J7.1, R51.2
unnamed: L2.1, U6.4 (L1)
unnamed: L2.2, U6.2 (L2)
unnamed: Q5.1 (B), R41.1
unnamed: Q5.2 (E), R44.2, U7.28 (~DTR)
unnamed: Q6.1 (B), R44.1
unnamed: Q6.2 (E), R41.2, U7.24 (~RTS)
unnamed: R1.2, U2.6 (OUTL)
unnamed: R3.2, U2.7 (OUTR)
unnamed: R4.2, U1.7
unnamed: R5.1, RV3.1
unnamed: R9.2, RV3.3
unnamed: R10.2, R12.1, U1.6 (-)
unnamed: R2.1, R11.2, RV3.2, U1.5 (+)
unnamed: R13.1, R24.2, RV4.2, U1.3 (+)
unnamed: R14.2, U1.1
unnamed: R15.1, RV4.1
unnamed: R21.2, RV4.3
unnamed: R22.2, R25.1, U1.2 (-)
unnamed: R23.1, R26.1, R29.2, U5.9 (FB)
unnamed: R27.1, R28.1, RV1.3
unnamed: R30.1, U4.3 (IN+)
unnamed: R32.1, U4.4 (IN-)
unnamed: R35.2, R36.1, U6.10 (FB)
unnamed: R40.1, U7.9 (~RSTb)
unnamed: R49.1, U8.2 (PROG)
unnamed: R54.2, U3.35 (TXD0)
unnamed: R55.2, U3.34 (RXD0)
PA_UNMUTE: U3.30 (IO18), U4.1 (~SD)
PCM_UNMUTE: U2.17 (XSMT), U3.16 (IO13)
PWR_SW: R33.2, SW1.5 (B), U3.36 (IO22)
TUNE_POT: C19.1, RV2.2, U3.6 (IO34)
VBAT_SNS: C26.1, R37.2, R38.1, U3.7 (IO35)
VBUS: BT1.1 (+), BT2.1 (+), C34.1, SW1.2 (B), U8.5 (BAT)
VDD: C27.1, R40.2, U7.6 (VDD)

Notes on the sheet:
PWM: 16kHz with 40% on cycle. Must not be low!

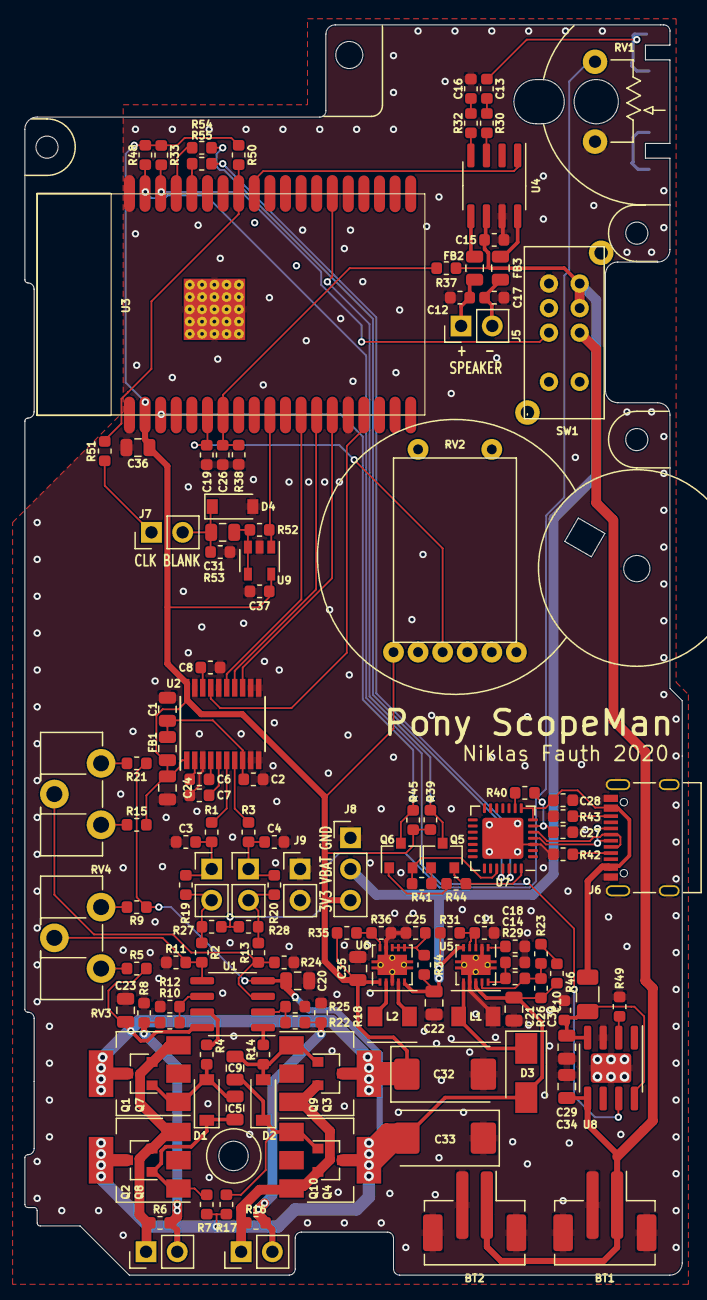
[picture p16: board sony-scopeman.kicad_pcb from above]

Board: 2 copper layers, 53.5 x 101.8 mm, 135 parts (0 on the bottom side), 87 nets.

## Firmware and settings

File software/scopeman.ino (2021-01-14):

/*
  Driving deflection coils with an external DAC using ESP32
  
  Copyright (C) 2020 Niklas Fauth
  This program is free software: you can redistribute it and/or modify
  it under the terms of the GNU General Public License as published by
  the Free Software Foundation, either version 3 of the License, or
  (at your option) any later version.
  This program is distributed in the hope that it will be useful,
  but WITHOUT ANY WARRANTY; without even the implied warranty of
  MERCHANTABILITY or FITNESS FOR A PARTICULAR PURPOSE.  See the
  GNU General Public License for more details.
  You should have received a copy of the GNU General Public License
  along with this program.  If not, see <http://www.gnu.org/licenses/>.
*/

#include "BluetoothA2DPSink.h"
#include <Arduino.h>
#include "driver/i2s.h"

BluetoothA2DPSink a2dp_sink;

#define CODEC_EN   13
#define SPEAKER_EN 18
#define FLYBACK    19
#define TUNE       34
#define SWITCH     22 // This changes the mode of operation. 1 = BT Audio; 0 = Lorentz Attractor Simulation

#define BUFFER_LEN 400

uint32_t buf[BUFFER_LEN];

int16_t x_buf[BUFFER_LEN];
int16_t y_buf[BUFFER_LEN];
int16_t z_buf[BUFFER_LEN];

int i2s_num = 0;

i2s_config_t i2s_config = {
    .mode = (i2s_mode_t) (I2S_MODE_MASTER | I2S_MODE_TX),
    .sample_rate = 48000,
    .bits_per_sample = (i2s_bits_per_sample_t)16,
    .channel_format = I2S_CHANNEL_FMT_RIGHT_LEFT,
    .communication_format = (i2s_comm_format_t) (I2S_COMM_FORMAT_I2S | I2S_COMM_FORMAT_I2S_MSB),
    .intr_alloc_flags = 0, // default interrupt priority
    .dma_buf_count = 32,
    .dma_buf_len = 256,
    .use_apll = false
};

static const i2s_pin_config_t pin_config = {
    .bck_io_num = 12,
    .ws_io_num = 27,
    .data_out_num = 14,
    .data_in_num = I2S_PIN_NO_CHANGE
};

uint32_t calc_buf_pos(int16_t x, int16_t y) { // +/- 1024
  uint16_t x_i = x*2;
  uint16_t y_i = y*2;
  uint32_t buf;

  buf = x_i | y_i << 16;
  return buf;
}

float x=0.01;
float y,z;

float a = 10.0;//10.;
float b = 28.0;//28.;
float c = 2.667;//2.66;
float dt = 0.015;
float dx, dy, dz;

void fillBuffer(uint16_t sz, float rot) {
  
  dx = (a * (y -x)) * dt;
  x = x + dx;

  dy = (x*(b-z)-y)  * dt;
  y = y + dy;

  dz = ((x*y)-(c*z))* dt;
  z = z + dz;

  float scale = 1.3;

  x_buf[sz/2] = (x*64) * scale;
  y_buf[sz/2] = (y*64) * scale;
  z_buf[sz/2] = (z*64 - 1200) * scale;
  
  //Serial.println(x_buf[sz/2]);
  
  for(uint16_t i = 0; i < sz/2; i++) {
    x_buf[i] = x_buf[i+1];
    y_buf[i] = y_buf[i+1];
    z_buf[i] = z_buf[i+1];
  }

  for(uint16_t i = sz/2+1; i < sz; i++) {
    x_buf[i] = x_buf[sz-i];
    y_buf[i] = y_buf[sz-i];
    z_buf[i] = z_buf[sz-i];
  }

  float sin_z = sin(rot);
  float cos_z = cos(rot);

  float sin_x = sin(rot * 0.5);
  float cos_x = cos(rot * 0.5);

  for(uint16_t i = 0; i < sz; i++) {

    // rotate Z axis
    int new_x = x_buf[i] * cos_z - y_buf[i] * sin_z;
    int new_y = x_buf[i] * sin_z + y_buf[i] * cos_z;

    // rotate ZY axis
    new_x = z_buf[i] * cos_x - new_y * sin_x;
    new_y = z_buf[i] * sin_x + new_y * cos_x;

    buf[i] = calc_buf_pos(new_x, new_y - 150);
  }
}


void setup() {
  pinMode(CODEC_EN, OUTPUT);
  digitalWrite(CODEC_EN, HIGH);

  pinMode(SPEAKER_EN, OUTPUT);
  digitalWrite(SPEAKER_EN, HIGH);

  ledcSetup(0, 16000, 8);
  ledcAttachPin(FLYBACK, 0);
  ledcWrite(0, 100);

  Serial.begin(115200); 
}
 
   
float rotation = 0;
uint8_t sw_mode = 1;

void loop() {
  if (digitalRead(SWITCH) == 0) {
    if (sw_mode == 0) { // Switch to Video Mode
      i2s_driver_uninstall((i2s_port_t)i2s_num);
      btStop();
      //initialize i2s with configurations above
      i2s_config.dma_buf_count = 2;
      i2s_config.dma_buf_len = BUFFER_LEN/2;
      i2s_driver_install((i2s_port_t)i2s_num, &i2s_config, 0, NULL);
      i2s_set_pin((i2s_port_t)i2s_num, &pin_config);

      sw_mode = 1;
    }
  } else {
    if (sw_mode == 1) { // Switch to BT Audio Mode
      i2s_config.dma_buf_count = 32;
      i2s_config.dma_buf_len = 256;
      i2s_driver_uninstall((i2s_port_t)i2s_num);
      a2dp_sink.set_pin_config(pin_config); 
      a2dp_sink.set_i2s_config(i2s_config); 
      a2dp_sink.start("Sony Scopeman");
      
      sw_mode = 0;
    }
  }

  if (sw_mode == 1) { // Video Mode
    fillBuffer(BUFFER_LEN, rotation);
    i2s_write_bytes((i2s_port_t)i2s_num, (const char *)&buf, i2s_config.dma_buf_len * 8, 100);
    dt = analogRead(TUNE) / 100000.0f;
  
    rotation = rotation + 0.001;
  
    if (rotation > M_PI_2 * 720.0) {
      rotation = 0;
    }
  } 
}

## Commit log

2020-12-17 Initial import
    [bom.csv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]
2020-12-17 Added schematic pdf
2020-12-17 removed old gerber
    [bom.csv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]
2021-01-13 Add: Pictures for Instruction
    [sony-scopeman-B_Cu.gbl, sony-scopeman-B_Mask.gbs, sony-scopeman-B_Paste.gbp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]
2021-01-14 cleaned up Arduino code
